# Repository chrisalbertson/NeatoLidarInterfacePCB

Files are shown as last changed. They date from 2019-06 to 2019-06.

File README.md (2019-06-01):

# Neato LIDAR Interface PCB

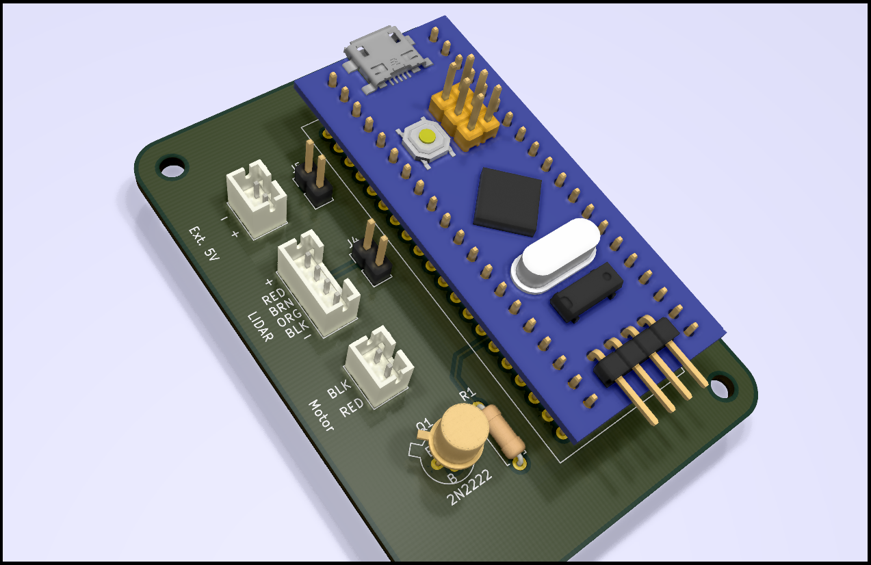
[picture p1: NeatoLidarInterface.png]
PCB Image


These are KiCAD design files for an interface PCB for the LIDAR units used in Neato XV-11 and Botvac vacuum cleaners.
This PCB and it's firmware is very much like the open source product sold by GetSurreal.com This version of their idea
uses a less expensive but much more powerfull (STM32 based) plug-in modual and also allows for external power.

This board (with the firmware from my other repository xxx) has the following features:
* Conect to the LIDAR using the native cable on the LIDAR unit
* Connects to any computer using USB.  It enumerates are a serial port.
* controls the speed of the mtor using a PID controller.  I find that regulation is better than 0.5%
* Sends raw LIDAR data over the USB cable
* Implements a simple CLI comand interface for test and dignostics and for setting and storing parameters in the interface's FLASH memory
* This interface board uses a generic STM32F103 (Blue Pill) borad for the comput unit.  These cost $2 on eBay.  Doing this means all the tiny SMD parts are already soldered and you just push the board in as if it were a 40-pid DIP IC.
* This PCB exactly fits in a 3D printable stand I designed.  There are two stands one for XV-11 and one for Botvac.

### jumper pins
Instructions for how to jumpper the board are on the back side silk screen.  Youhave the otopn to use either type LIDAR and to power the LIDAR either from USB or an external 5V power supply.  The external supply would only be required of you are connecting to an unpowered hub. (A 500 mA supply is more than large enough.)

### Which type of LIDAR to use?
Both work equally well but there are differences.
#### XV-11
This unit look the best and is the most compact but it uses a slip ring and mechanical brushes to comutate the data and powert othe spinner scanner.   It seems to work but all mechanical brushes will eventualy fail.
#### Botvac
The blastic base has a ugly looking shape.  But the slip ring has been repalced by a non-contact system.  Power is transmitting using a pair of coils that work like a transformer where the secondary is spinning and the data is send up and down the spin axis by a wiresless (and fiberless) optical link.  The only down side is that this LIDAR uses about down the amount of current.   

### ROADMAP
The processor used here is much faster and has more FLASH memory than the original version.   I plan to use this to enable some more features.  Some of them might be:
* Add a small LCD display to visualize the laser scan data and varify proper operation
* Add a a switch or button to allow simple configuration with no computer connected
* Add a ROS_serial interface mode where the conversion to laser-scan or even point cloud data format is done on theis interface PCB.

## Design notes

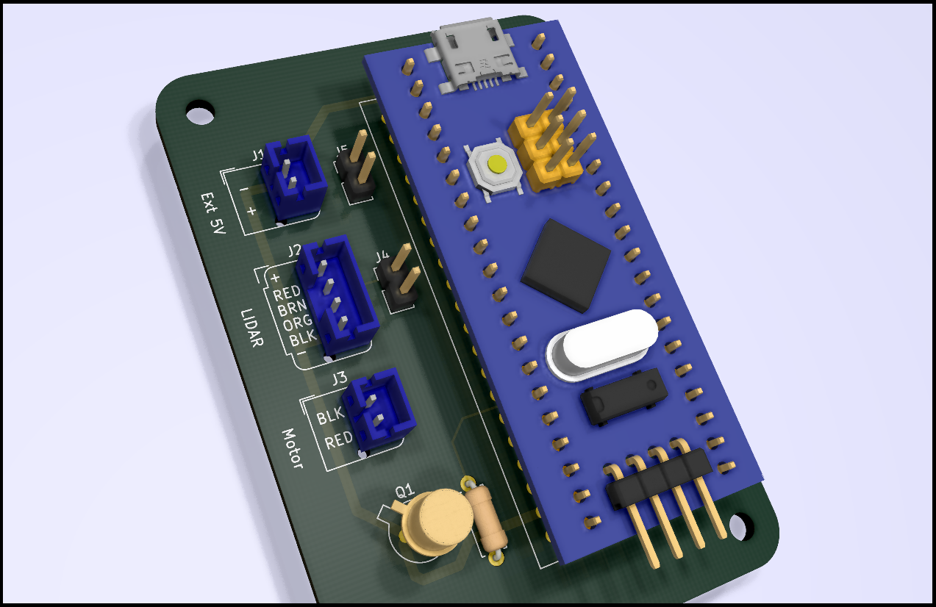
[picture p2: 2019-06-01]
NeatoLidarInterfaceRT.png

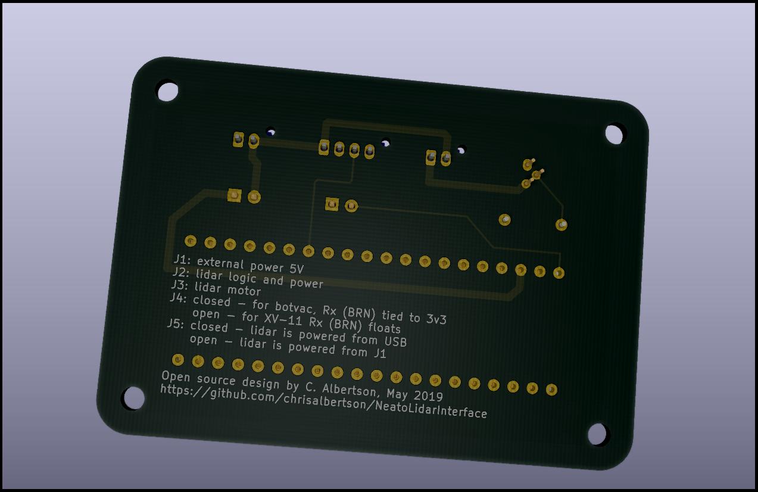
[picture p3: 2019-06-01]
NeatoLidarInterfaceBackRT.jpg

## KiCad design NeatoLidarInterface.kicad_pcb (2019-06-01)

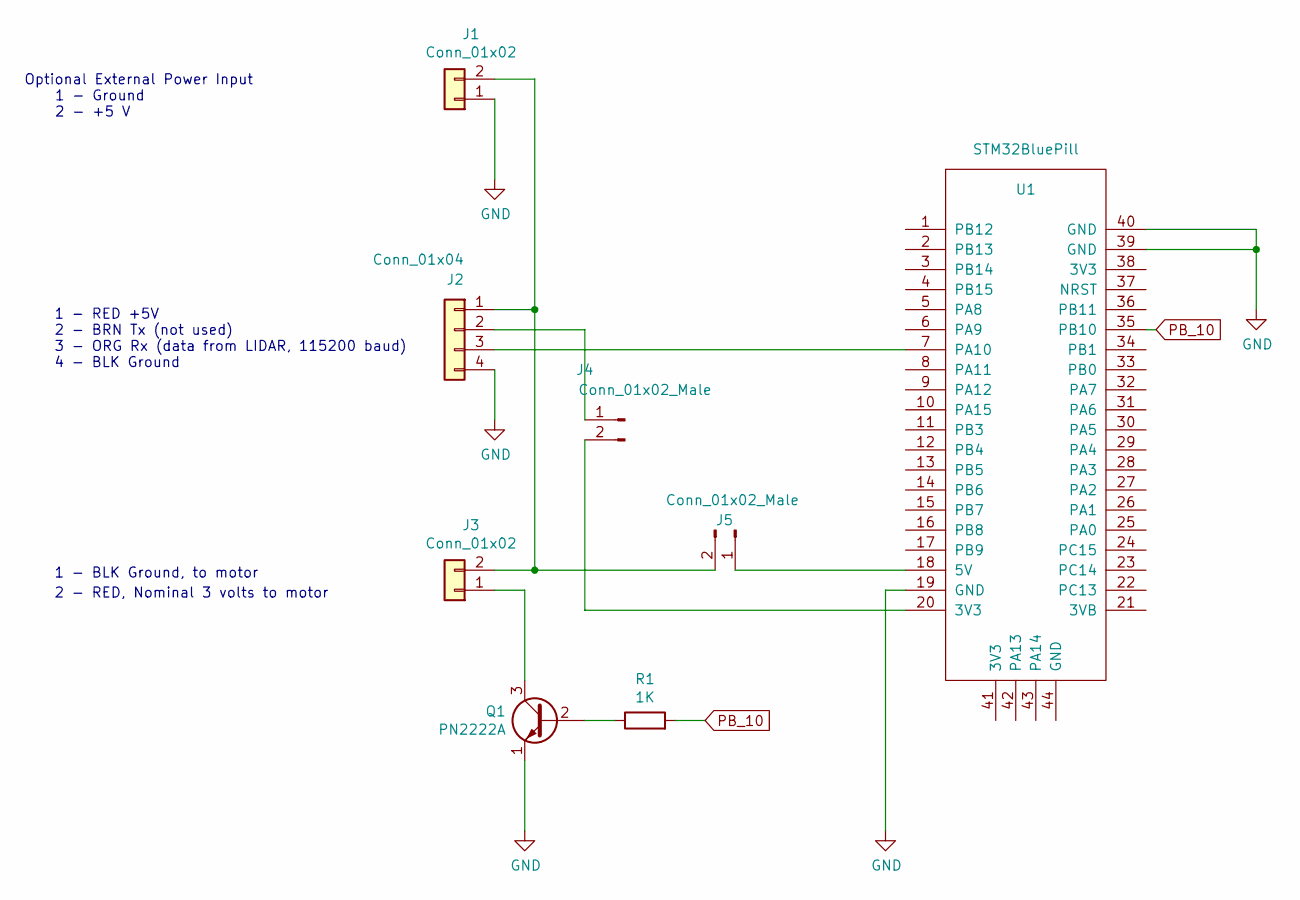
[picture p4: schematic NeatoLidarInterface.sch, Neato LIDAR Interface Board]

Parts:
J1, J3: Conn_01x02; JST_PH_B2B-PH-K_1x02_P2.00mm_Vertical
J2: Conn_01x04; JST_PH_B4B-PH-K_1x04_P2.00mm_Vertical
J4, J5: Conn_01x02_Male; PinHeader_1x02_P2.54mm_Vertical
Q1: PN2222A; TO-18-3
R1: 1K; R_Axial_DIN0207_L6.3mm_D2.5mm_P7.62mm_Horizontal
U1: STM32BluePill

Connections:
GND: J1.1, J2.4, Q1.1 (E), U1.19 (GND), U1.39 (GND), U1.40 (GND)
unnamed: J1.2, J2.1, J3.2, J5.2
unnamed: J2.2, J4.1
unnamed: J2.3, U1.7 (PA10)
unnamed: J3.1, Q1.3 (C)
unnamed: J4.2, U1.20 (3V3)
unnamed: J5.1, U1.18 (5V)
unnamed: Q1.2 (B), R1.1
PB_10: R1.2, U1.35 (PB10)

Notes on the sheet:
1 - RED +5V 2 - BRN Tx (not used) 3 - ORG Rx (data from LIDAR, 115200 baud) 4 - BLK Ground
1 - BLK Ground, to motor
2 - RED, Nominal 3 volts to motor
Optional External Power Input 1 - Ground 2 - +5 V

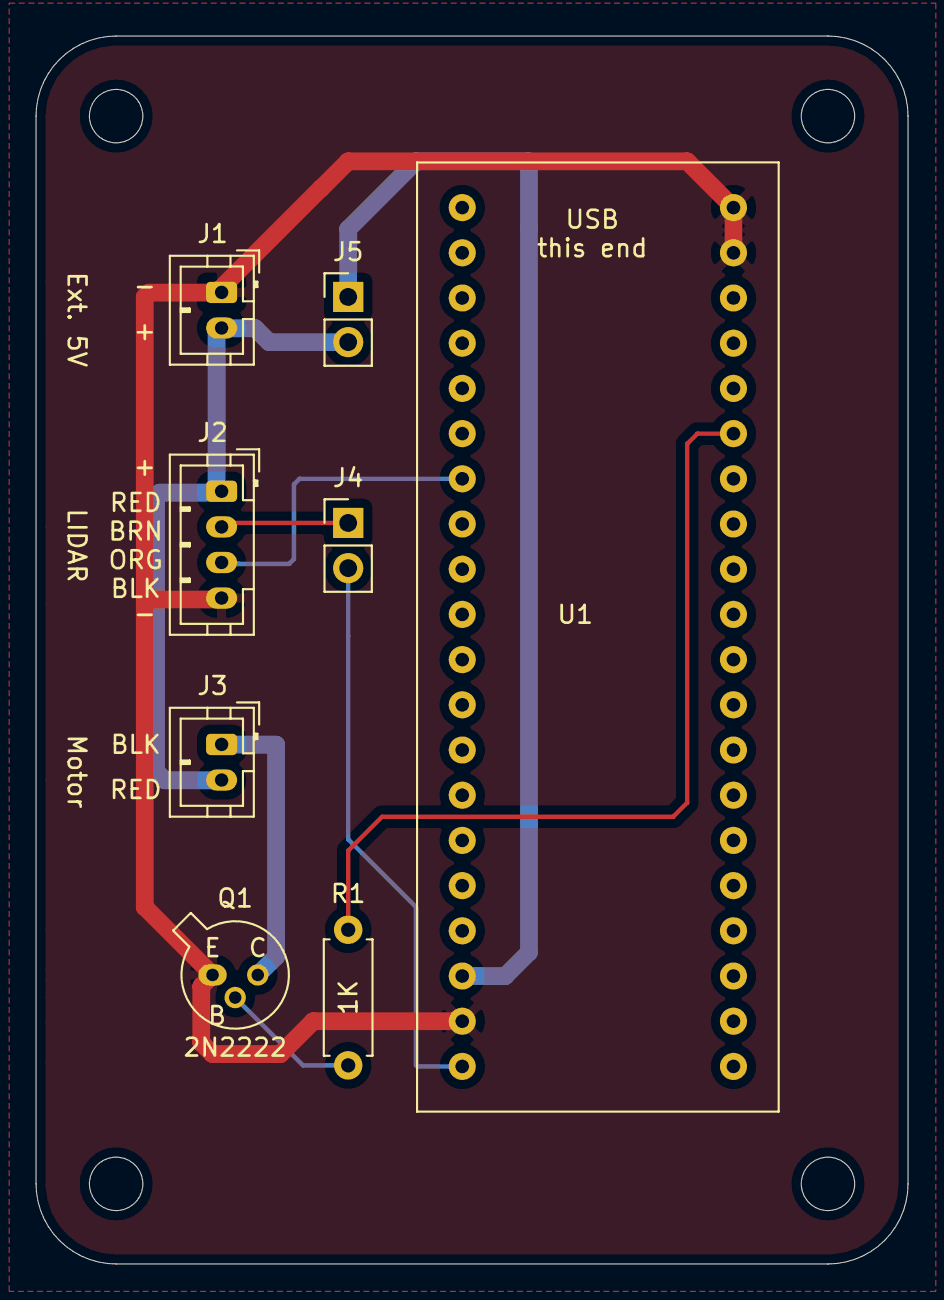
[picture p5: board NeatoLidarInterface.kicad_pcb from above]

Board: 2 copper layers, 49.0 x 69.0 mm, 8 parts (0 on the bottom side), 9 nets.

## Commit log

2019-06-01 inital checkin
    [NeatoLidarInterface-B_Cu.gbl, NeatoLidarInterface-B_Mask.gbs, NeatoLidarInterface-B_Paste.gbp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]
2019-06-01 improve JST footprint, add copper fill
    [NeatoLidarInterface.kicad_pcb, NeatoLidarInterface.sch]
